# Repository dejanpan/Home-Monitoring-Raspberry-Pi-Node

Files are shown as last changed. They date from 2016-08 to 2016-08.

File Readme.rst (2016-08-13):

----------
Smart Home
----------
In the last month I finally had some spare to scratch the surface on the latest of web backend and frontend development. In particular I got my fingers wet with nodejs and javascript. Back from where I originally come we love the saying `join useful and pleasant` and so I went and built a very custom and cheap **smart home system**. A system that guards our flat, watches over the fridge content and lets us control the lights through a convenience of a cell phone. Sounds cool? Lets take a tour then.

-------------
Home Security
-------------
You type in the web address of our home server (RaspberryPI) and you are offered the following selection:

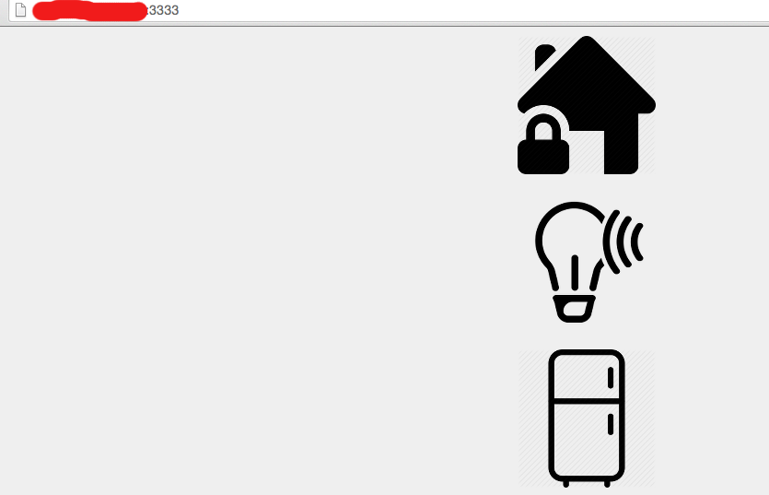
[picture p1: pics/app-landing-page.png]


Lets get to know our security guard (PI, PI camera and PIR motion sensor).

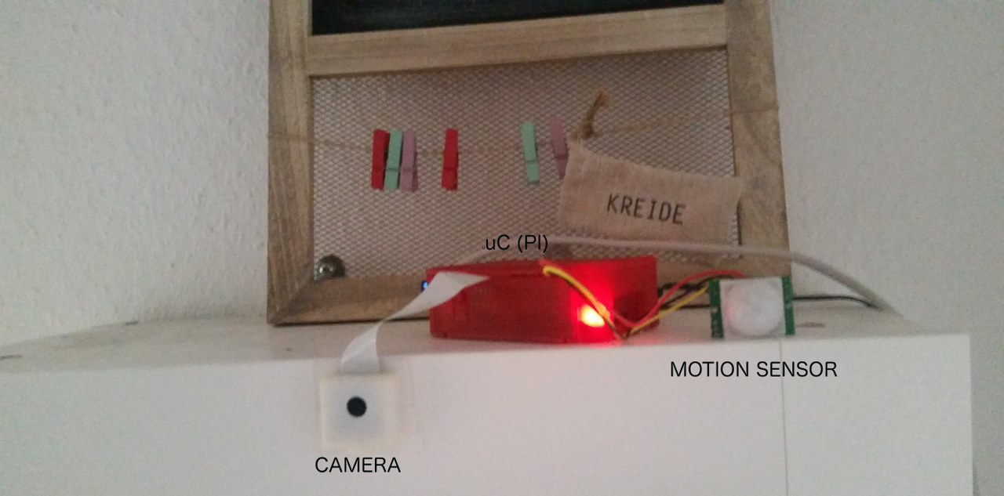
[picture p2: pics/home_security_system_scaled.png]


Interface offers live view into the appartment, switch to arm/disarm an alarm and link to the recorded snapshots whenever the alarm got triggered. The motion sensor senses a change of temperature as soon as someone enters through the door.

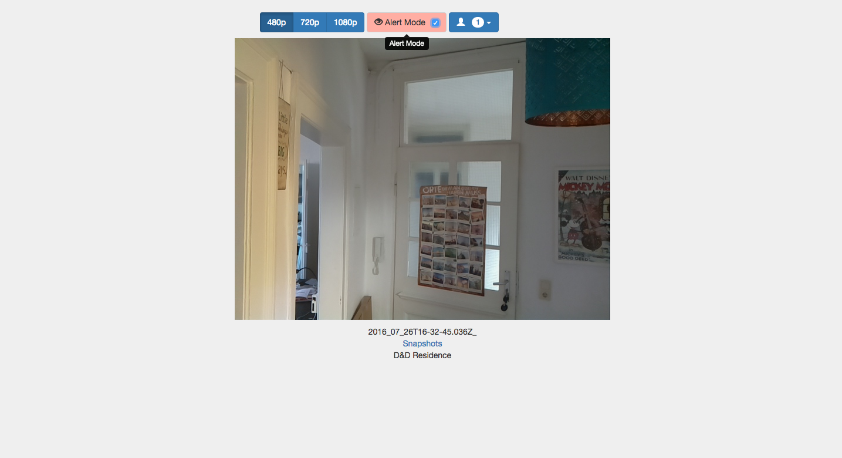
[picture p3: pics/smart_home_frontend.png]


It also sends emails



and comes with the gallery to watch burglars whenever you are bored

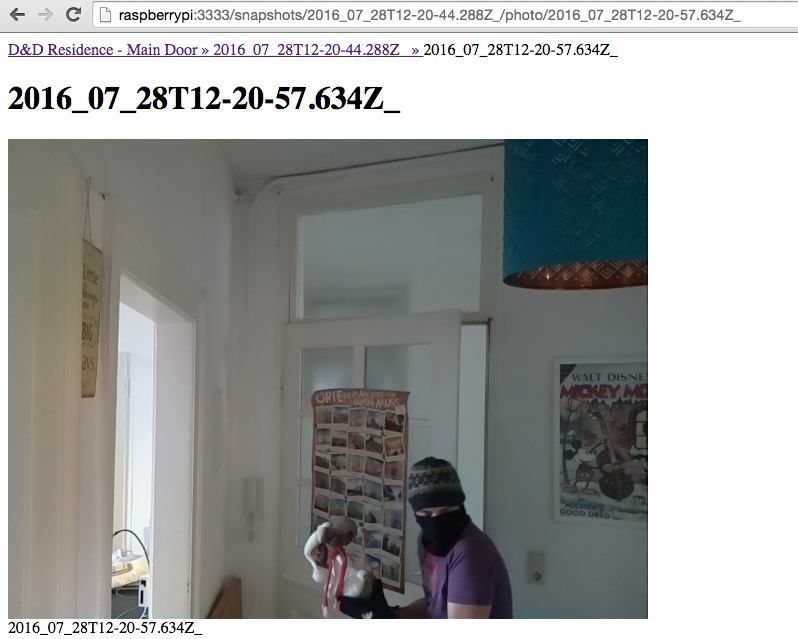
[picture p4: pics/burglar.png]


---------------------
What is in my Fridge
---------------------

Do you know this feeling when you stand in the supermarket and scratch your head trying to remember if you have milk in your fridge? Smart home to the rescue and no more scratching! Lets go back to the landing page:



Click on fridge icon and ... you will end up in our fridge gallery:

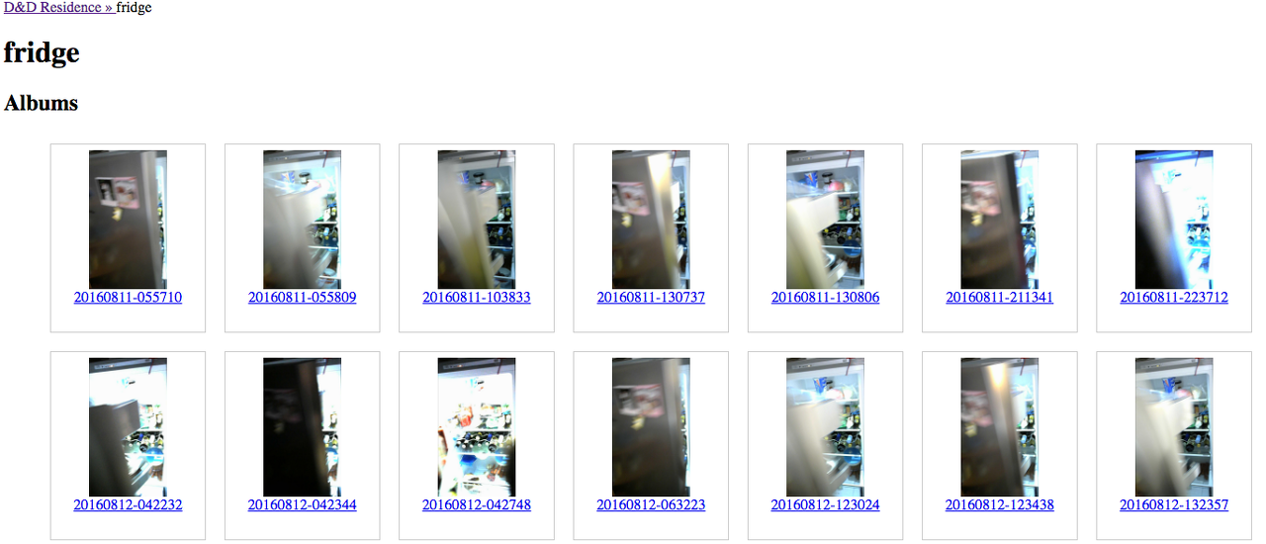
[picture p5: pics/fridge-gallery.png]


So is milk there? Nope! Remember I am watching this from the supermarket:)

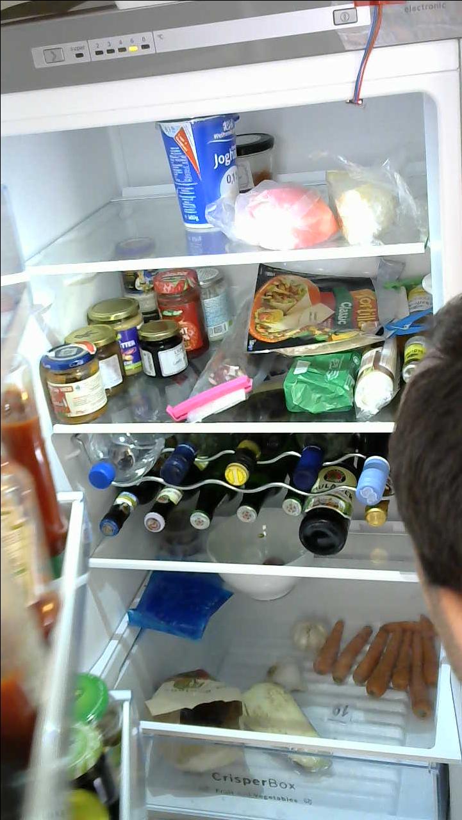
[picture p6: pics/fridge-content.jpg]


How does it work? Assuming you have a fridge, you order a PI:

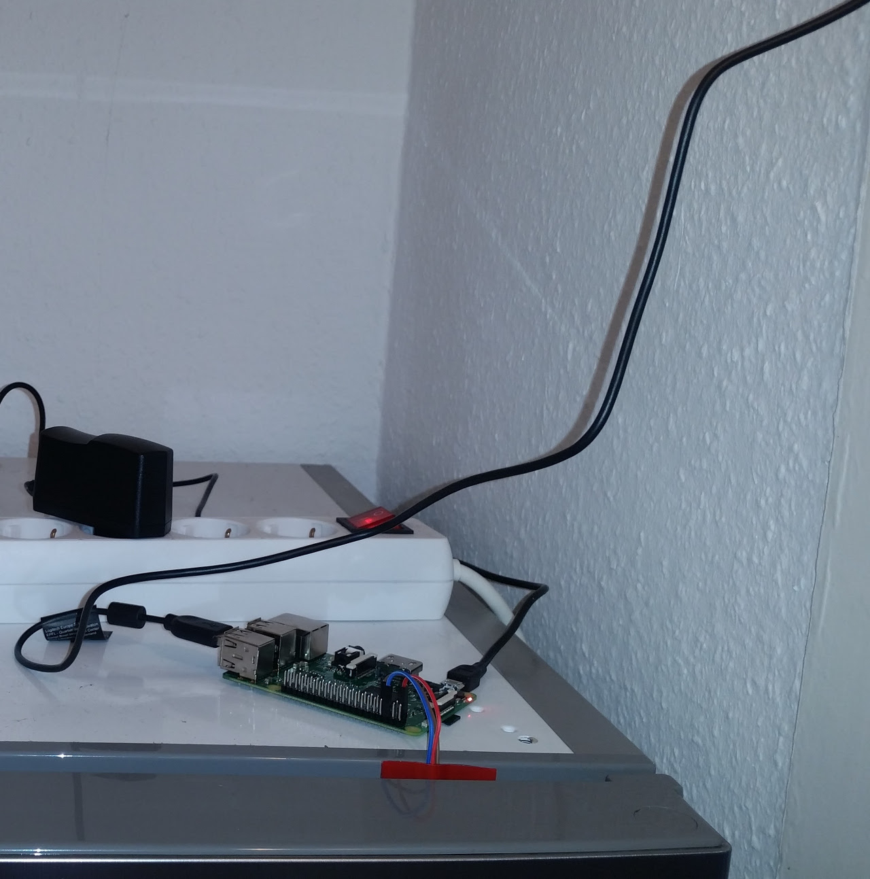
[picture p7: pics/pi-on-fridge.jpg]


a web cam

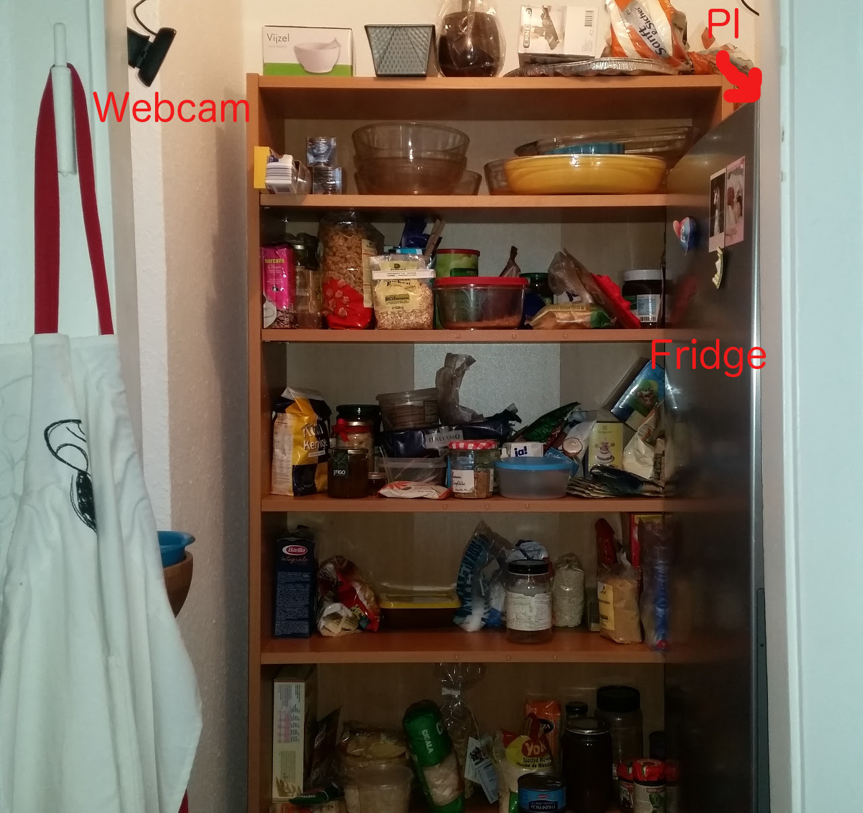
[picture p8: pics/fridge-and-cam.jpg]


a light sensor and voila here you go. Every time you open the fridge, the light inside is turned on and this event triggers recording of fridge images until the fridge is closed again (and thus the light turned off).

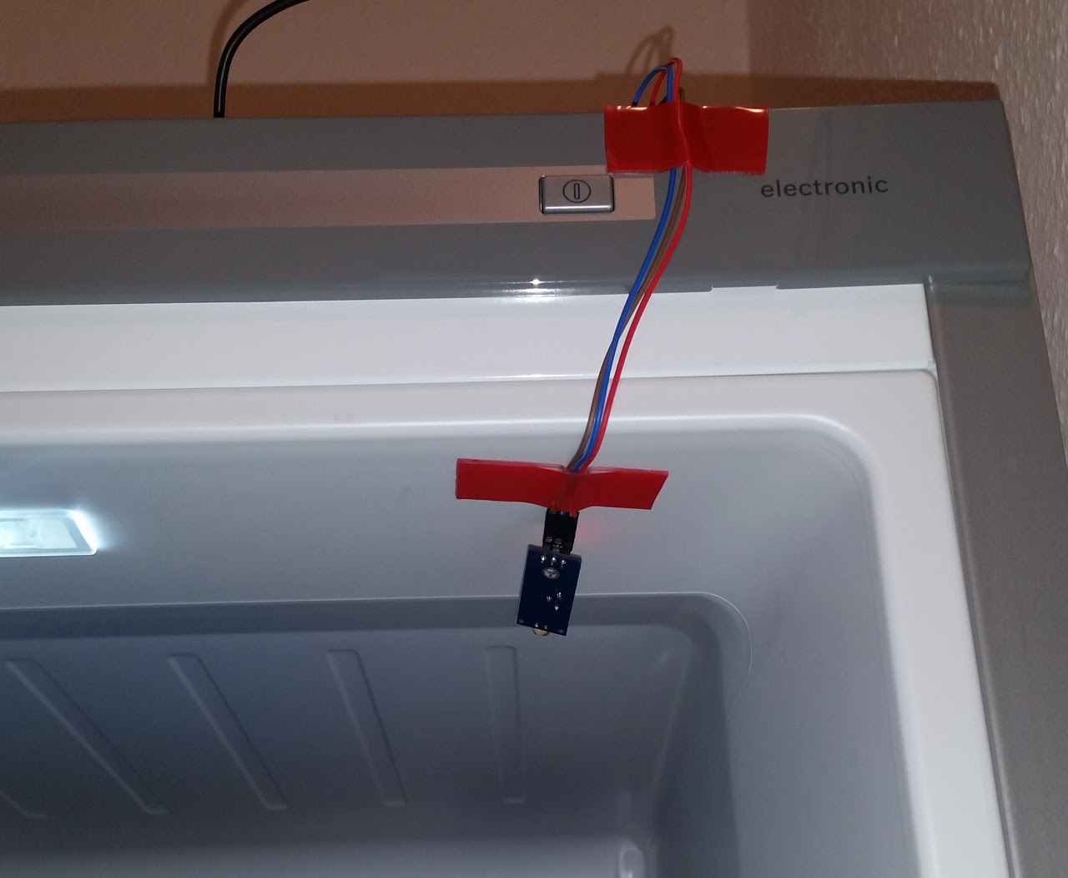
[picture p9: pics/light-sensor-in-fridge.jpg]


-------------------
Remote Light Switch
-------------------
How about that feeling when you are wrapped in the blanket in your bed and the light is still turned on? Worry not, we have a solution for this too. Back to landing page 



and after clicking on the bulb icon you can turn off the light from your cell phone.

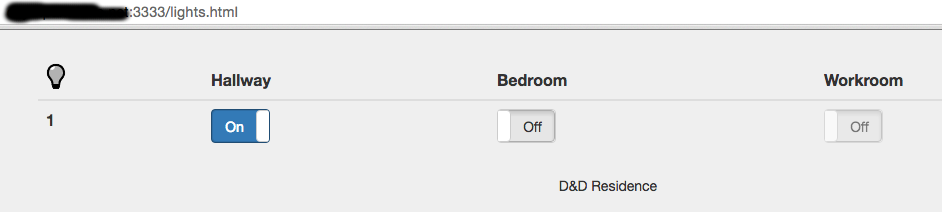
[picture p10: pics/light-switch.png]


.. Now it is bright:
	
  

.. and now it is dark:

  

Remote light switch ensemble:

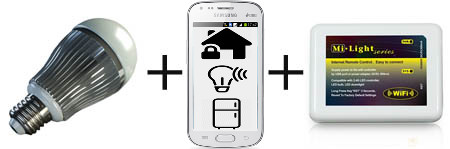
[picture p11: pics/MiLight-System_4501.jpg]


For technical implementation and details see: `documentation <documentation.rst>`_.

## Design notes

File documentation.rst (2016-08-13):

Software part of this project is based on the excellent project of `Andrei <https://github.com/orosandrei/Home-Monitoring-Raspberry-Pi-Node>`_. That was a great jump start.

Below is a list of things that I need to thoroughly document when I get some more time (return from vacations).

-----------
Install PI
-----------
- https://www.raspberrypi.org/documentation/installation/noobs.md
- change hostname in /etc/hosts and /etc/hostname
- apt-get dist-upgrade
- apt-get install emacs
- apt-get install tmux
- git clone https://github.com/jacksonliam/mjpg-streamer.git
- sudo apt-get install cmake
- sudo apt-get install libjpeg9-dev
- sudo apt-get install python-yaml

-----------
Unsorted
-----------
- Light sensor: http://www.uugear.com/portfolio/using-light-sensor-module-with-raspberry-pi/
- Domain name and no-ip
- gpio-admin:

  - https://www.npmjs.com/package/pi-gpio
  - fix for the path: https://github.com/quick2wire/quick2wire-gpio-admin/pull/6
  - Needed to install pi-gpio version 0.0.8 because of this line: https://github.com/rakeshpai/pi-gpio/commit/c6495b0b4f3756a0ec55a6e3d98b7f71b2cb5822

- pinout: https://pinout.xyz/
- setting up vsftp: http://www.liquidweb.com/kb/how-to-install-and-configure-vsftpd-on-ubuntu-14-04-lts/
- mjpeg-streamer:  https://github.com/dejanpan/Home-Monitoring-Raspberry-Pi-Node/commit/08873e3a4a110bb7183767243f2630ab9c6e41fb
- Test programs:

  - ftp
  - test pin out
  - pir.py
  - See https://github.com/dejanpan/Home-Monitoring-Raspberry-Pi-Node/tree/master/test-programs

- Motion detection is recognised as 1
- Milight: http://iqjar.com/jar/home-automation-using-the-raspberry-pi-to-control-the-lights-in-your-home-over-wi-fi/

----------
Framework
----------
- short architecture explanation
- what is express, node-gallery, http, nodemailer, socket.ip, pi-gpio, node-milight-promise
- configuration file

-----------------------------
Home Server and Accessibility
-----------------------------
- register domain
- install client on your raspberry
- crontab job

- image streaming (mjpg-streamer)
- for computer and mobile (bootstrap)
- motion detection
- email notification about intrusion
- snapshots during intrusion (node-gallery)

- milight bulb
- milight controller
- bootstrap-toggle

- image streaming (mjpg-streamer)
- light detection
- moving awvrage window
- python and subprocess
- rsync image upload
- snapshots while the fridge was open (node-gallery)
- wideangle camera and case

-----------------------------
Are my Windows/Doors Closed?
-----------------------------
- zwave magnetic switch
- zwave stick

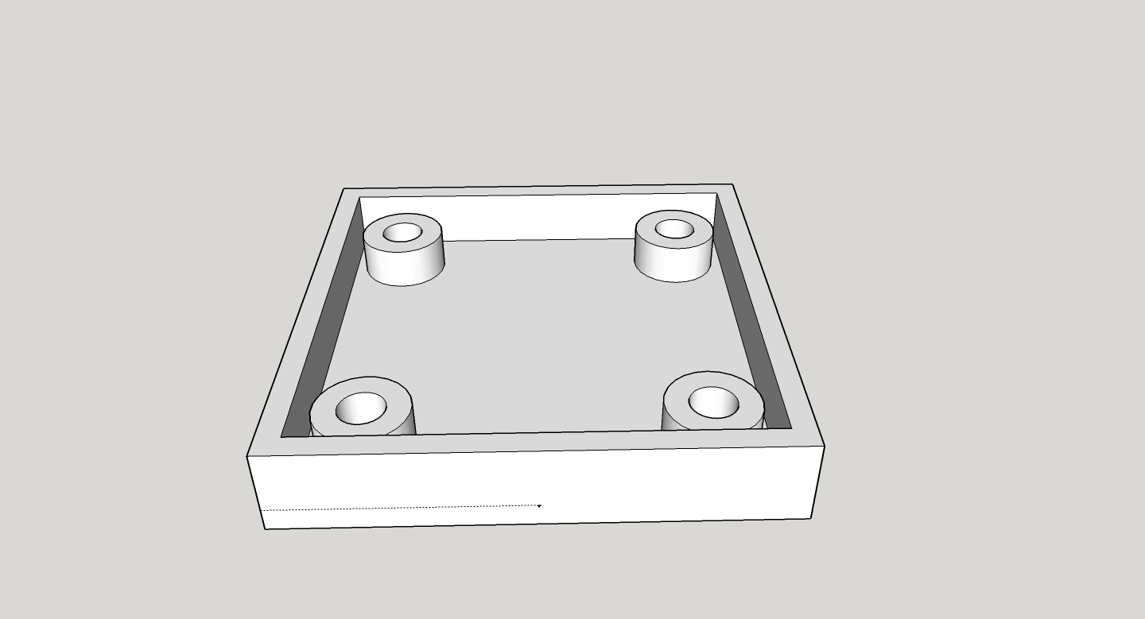
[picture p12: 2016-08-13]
pics/flp_wide_angle_cam_case.jpg

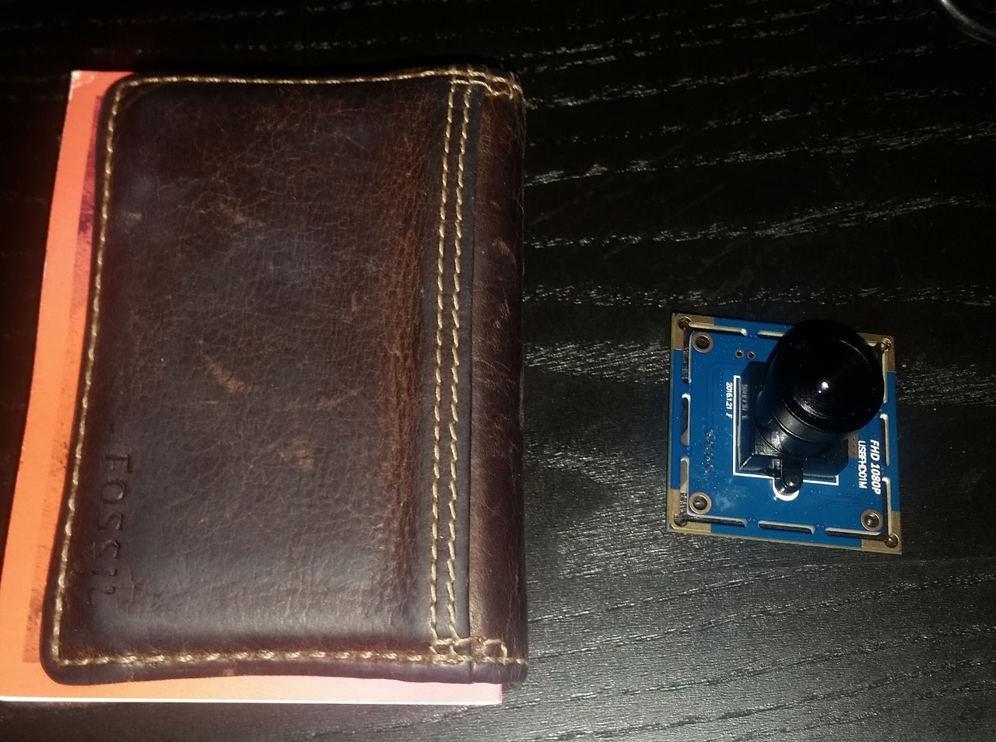
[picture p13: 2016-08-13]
pics/wideangle-cam.jpg

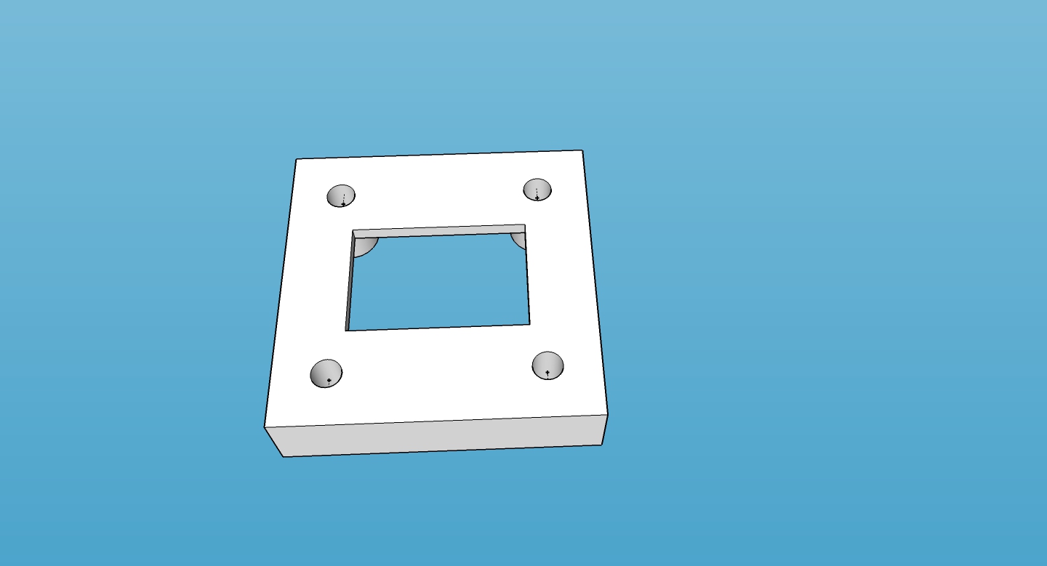
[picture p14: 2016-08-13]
pics/flp_wide_angle_cam_case_top.jpg

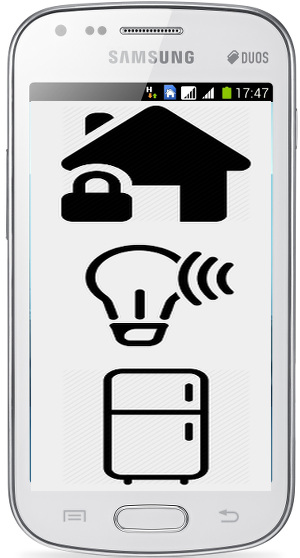
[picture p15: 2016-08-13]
pics/cellphone.jpg

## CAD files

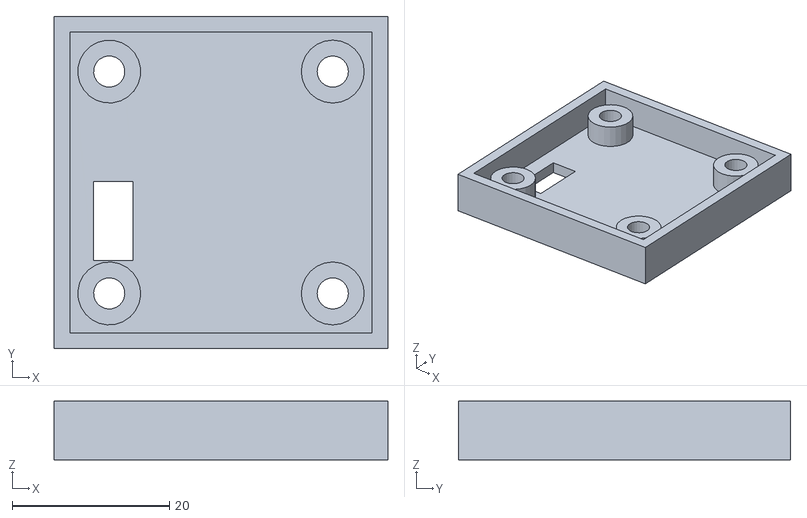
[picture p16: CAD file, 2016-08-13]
pics/flp_wide_angle_cam_case_group.stl
42.4 x 42.2 x 7.50

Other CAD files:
pics/flp_wide_angle_cam_case_group_fixed.stl
pics/flp_wide_angle_cam_case.stl
pics/flp_wide_angle_cam_case.skp
pics/flp_wide_angle_cam_case_top.skp

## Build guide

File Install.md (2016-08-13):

# Home Monitoring with Raspberry Pi and Node.js
 
Home Monitoring with Raspberry Pi and Node.js
 
## Description  
 
The project is designed as a end to end solution for a DIY **Home Monitoring & Intruder Alert system**. Besides offering a live video stream on any device (web responsive client), it also actively monitors for movement with the help of a *PIR sensor*.
 
If an *Alarm* is triggered, you get a SMS notification on your phone and the snapshots taken during the *Alarm time span* (customizable - default is 1 minute) are uploaded via FTP to your server.  
 
Activation / Deactivation of the *Alarm Mode* can be done in 2 ways:  
 1. from the Web Client user interface 
 2. with a Button - for convenience reasons: it is faster than connecting from your phone / pc & toggling the Alert Mode checkbox 
    - there is a 10 seconds customizable delay which allows you to move out of the PIR sensor range 
    - a Led indicates the Alarm Mode enabled/disabled status 
 
In order to avoid false positives from the PIR motion sensor, extra checks were added - a detection counter & detection interval. The Alarm gets triggered when the sensor detects movement 3 times in 5 seconds (both values configurable in code).
 
## Technology 
 
The project was developed using: 
- [Raspberry Pi](http://raspberrypi.org) - [raspbian](https://www.raspbian.org/), brick button & led, Pir sensor
- [Node.js](https://nodejs.org/en/) - for the main application 
- [Mjpg_streamer](http://sourceforge.net/projects/mjpg-streamer/) - to generate the video stream 
- Shell scripting - for easy application start (interactive & background) 
- Htms/Css/Javascript + [Bootstrap](http://getbootstrap.com/) - the web client  
 
## Project components 
 
### Hardware 
Pir Button Led RaspberryPi Gpio
```javascript
this.Gpio = require('pi-gpio');
this.Hardware = { MotionSensor : 8, Led : 26, Button : 12 };
```
- Raspberry Pi 
  - I used *Model B Revision 2* with *Raspbian* - any model should be Ok, just be careful with the Gpio configuration pin mappings, they can differ 
  - Generic USB webcam (compatible with Raspberry Pi & Raspbian) 
  - You can find a comprehensive list here http://elinux.org/RPi_USB_Webcams  
  - I used a very old 2MP one which seems to work out of the box with the generic drivers 
- Led & Button  
Brick Button Led
- PIR motion sensor 

PIR sensor
  - The one I used is available here https://www.sparkfun.com/products/13285  
  - It normally connects to Analog Input (ex. on Arduino); however you can use it with Digital as well if you connect a 10K resistor between VCC & Signal  
PIR resistor 
  - To make things easier you can purchase this sensor https://www.adafruit.com/products/189 and skip the soldering part (+ this one has configurable sensitivity built-in, so you might be able to skip the one implemented in the code)    
 
### Node application 
 
#### Dependencies 
- express: ^4.12.3 
- ftp: ^0.3.10 
- http-auth: ^2.2.8 
- ini: ^1.3.4 
- pi-gpio: 0.0.7 
- socket.io: ^1.3.5 
- twilio: ^2.3.0 
 
The dependencies you install with NPM: 
```
npm install module --save
```
 
#### Generic ```Application.js```
It is the basic application object, defined to be reusable in other projects 
Contains the basic server code, generic config file read/write operations, generic Init & Execute & Exit methods implementations 
 
#### Home Monitoring ```ApplicationHM.js``` 
- config.ini file 
  - default video quality & alert mode settings
  - Twilio sms Api *Sid*, *Token*, *To* number, *From* number 
  - Ftp settings
- Authentication (digest http authentication) - defaults are **admin** & **password** :) 
  - You can change them from the ```htdigest``` file (nice helper tool here http://websistent.com/tools/htdigest-generator-tool/ ) 
  ```
  admin:Private:6982db7f1ddc36a0b47b5f8427dc3526
  ```

- Web Client application
  - Accessible from anywhere via [port forwarding](https://en.wikipedia.org/wiki/Port_forwarding)
  - Available also on mobile (responsive web client) 
- Monitoring - gets video from [Mjpg_streamer](http://sourceforge.net/projects/mjpg-streamer/) server and sends it to the connected app clients 
- [Mjpg_streamer](http://sourceforge.net/projects/mjpg-streamer/) was used as server, but if you prefer another tool like ffmpeg, you can easily replace it because of the loose integration via the ```start-webcam.sh``` script 

#### Alarm mode 
- Monitoring - via PIR sensor 
- Alarm - Sms notification (implemented with the help of [Twilio](https://www.twilio.com/sms)   text messaging API - very cool service, offers great Trial account for development 
- Alarm - Snapshots upload to server via Ftp 
 
### Web Client - responsive
 
The client application was designed to be accessible on all platforms (pc / tablet / mobile). 

Web Client  

#### Video streaming quality settings 
By default the 480p at 25fps is enabled (initial settings are loaded from the ```config.ini``` file) 

My webcam is a low-end 5+ years old 2mp device, but for those of you with better webcams I also added 720p & 1080p 

Video resolutions & fps can be configured from the ```/static/js/script.js``` file 
```javascript
//only check quality settings
if(ui.quality480p.prop('checked')) {
	appConfig.monitoring.quality = "640x480";
	appConfig.monitoring.fps = 25;
}
if(ui.quality720p.prop('checked')) { 
	appConfig.monitoring.quality = "1280x720";			
	appConfig.monitoring.fps = 25;
}
if(ui.quality1080p.prop('checked')) { 
	appConfig.monitoring.quality = "1920x1080";			
	appConfig.monitoring.fps = 25;
}
	
//send to server new config settings
socket.emit('update config quality', appConfig);
```
 
#### Alert Mode 
- initial state is loaded from the ```config.ini``` file 
- You can enable/disable monitoring from checkbox button in the UI 
- The state of the Alert Mode is shown both in the UI (the checkbox) but also by the LED 
- The physical Button can be also used to toggle the Alert Mode 
- All state changes are sent to all connected clients 
- If an Alarm is triggered, the UI checkbox button background will be changed to Red 
Alarm  

#### Connected Clients 
The dropdown shows a list of all connected clients (connection timestamp & IP) that are currently viewing the video stream  
Connected Clients List  

### Shell Scripts 
 
**start-app.sh**
- You can start the application in 2 modes: 
  - Interactive (for dev / testing): ```./start-app.sh```
  - Background: ```./start-app.sh -background```
```shell
#!/bin/bash
# application start in interactive or background mode
#arguments:  [-background]

cd /home/pi/Desktop/rpiWorkspace/Node/HomeMonitoring/

if [ "$1" = "-background" ]; then
	sudo nohup node ./App-home-monitoring.js &>log.txt &
else
	sudo node ./App-home-monitoring.js 
fi
```
  
**start-webcam.sh**
- Used by the application to enable/disable video streaming when clients are connected or when an Alarm is triggered by the PIR sensor. 
```shell
#!/bin/bash
# webcam video stream
# arguments:  [resolution] [port] [fps]

pkill mjpg_streamer

sudo nohup ./mjpg-streamer/mjpg_streamer -i "./mjpg-streamer/input_uvc.so -y -r $1 -f $3 -q 75" -o "./mjpg-streamer/output_http.so -n -p $2" &
```

## Application Execution Session example
Application Execution Session example  

---
 
**TO DO** 
- Port the application to Windows 10 Iot on Raspberry Pi 2 
- Support for uploading snapshots to cloud (OneDrive / Dropbox) when an Alarm is triggered 
 
**References** 
- Raspberry Pi https://www.raspberrypi.org/  
- Node - https://nodejs.org/en/  
- Mjpg_streamer http://sourceforge.net/projects/mjpg-streamer/  
- SMS Api - Twilio - https://www.twilio.com/sms  
- Bootstrap http://getbootstrap.com/ 
- App Webcam Icon - https://www.iconfinder.com/icons/71274/webcam_icon#size=128  

---
**Links**
- Blog post about project [Home Monitoring with Raspberry Pi & Node](http://andreioros.com/blog/home-monitoring-raspberry-pi-node/%20)
- [Hackster.io project page](https://www.hackster.io/andreioros) 
- twitter [@orosandrei](https://twitter.com/orosandrei)

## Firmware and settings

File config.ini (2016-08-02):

[monitoring]
alert=false
fps=10
width=640
height=480

[sms]
sid=
token=
to=
from=

[ftp]
server=localhost
port=21
user=ftpup
pass=ftpup
folder=/home/ftpup/

[email]
user=
password=
from=
to=
subject=
text=

[lights]
ip=192.168.178.54
delayBetweenCommands=75
commandRepeat=2

[lights.rooms.bedroom]
zone=2
name=bedroom
state=false

[lights.rooms.hallway]
zone=1
name=hallway
state=false

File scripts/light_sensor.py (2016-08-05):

import time
import datetime
import RPi.GPIO as GPIO
import subprocess
import sys, os
import yaml
import shutil
import math

from PIL import Image
import glob

from collections import deque
light_reading_cache = deque() # keep track of seen values
cum_sum = 0

def print_help():
        print("""
        Usage: light_sensor.py config.yaml
        """)

def load_config(file):
        with open(file, 'r') as stream:
                try:
                        config  = yaml.load(stream)
                except yaml.YAMLError as exc:
                        print(exc)
        return config

def configure_sensor(pin):
        GPIO.setmode(GPIO.BCM)
        GPIO.setup(pin,GPIO.IN)

#bright is low, dark is high
def is_light_on(counter, window_size, pin):
        if filter_signal(GPIO.input(pin), counter, window_size) == 0:
                return True
        else:
                return False

def filter_signal(val, counter, window_size):
        global cum_sum
        light_reading_cache.append(val)
        cum_sum += val
        if counter < window_size:
                avg = cum_sum / float(counter)
                round_avg = int(round(avg))
        else:                           # if window is saturated,
                avg = cum_sum / float(window_size)
                cum_sum -= light_reading_cache.popleft()  # subtract oldest value
                round_avg = int(round(avg))
        return round_avg
                
def upload_snapshots(config, src):
        key = os.path.expanduser(config['ssh_key'])
        ssh  = 'ssh -i {}'.format(key)
        path = config['remote_path']
        print os.path.join(src,"")
        cmd = [ 'rsync', '-vaP',  '--progress', '-e', ssh,
                src, '{}@{}:{}'.format(config['user'], config['host'], os.path.join(path,"")) ]
        subprocess.check_call(cmd)

def rotate_snapshots(dirname, angle):
        for infile in glob.glob(dirname + "/*.jpg"):
                print("rotating ", infile)
                im = Image.open(infile)
                im.rotate(angle, expand=True).save(infile, 'JPEG')
        
def process(config):
        configure_sensor(config['pinout'])
        new_snapshots = False
        try:
                print("starting mjpg-streamer")
                cmd = [ config['script'], config['resolution'], str(config['fps']), str(config['port']) ]
                proc_mjpg = subprocess.Popen(cmd)
                counter = 1
                while True:
                        if is_light_on(counter, config['window_size'], config['pinout']):
                                #where to save images
                                dirname = time.strftime("%Y%m%d-%H%M%S")
                                if not os.path.exists(dirname):
                                        os.makedirs(dirname)
                                        
                                t_end = time.time() + config['snapshot_duration']

                                #grab snapshots
                                while is_light_on(counter, config['window_size'], config['pinout']):
                                        image_name = dirname + '/' + datetime.datetime.now().strftime("%Y%m%d-%H%M%S-%f") + '.jpg'
                                        wget_proc = subprocess.call(['wget',  'http://localhost:' + str(config['port']) + '/?action=snapshot', '-O', image_name], shell=False)
                                        time.sleep(1/config['fps'])
                                        new_snapshots = True
                                        
                        #upload them to main server (rsync)
                        if new_snapshots:
                                rotate_snapshots(dirname, config['angle'])
                                upload_snapshots(config, dirname)
                                shutil.rmtree(dirname)
                                new_snapshots = False
                                
                        #avoid counter overflow
                        if counter >= config['window_size']:
                                counter = 2 * config['window_size'] #could be any value > window size
                        
                        counter = counter + 1
                        time.sleep(0.1)
        except KeyboardInterrupt:
                print("Received KeyboardInterrupt, terminating processes.")
        finally:
                if proc_mjpg is not None and proc_mjpg.poll() is None:
                        try:
                                proc_mjpg.terminate() # send terminate signal
                                proc_mjpg.communicate() # wait for the process to terminate
                                subprocess.call(['pkill', 'mjpg_streamer']) #above 2 lines do not kill mjpg-streamer                      
                        except:
                                print("Failed to terminate process with PID %s: %s" % (proc_mjpg.pid, sys.exc_info()[0]))

if __name__ == '__main__':
        if len(sys.argv) != 2:
                print_help()
                exit(-1)
        config = load_config(sys.argv[1])
        process(config)
        # signal = [0, 0, 0, 0, 0, 1, 1, 1, 1, 1, 1]
        # counter = 1
        # for i in signal:
        #         print(filter_signal(i, counter))
        #         counter = counter + 1
                

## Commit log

2016-07-13 fixed starting of the app from nodejs application
    [config.ini]
2016-07-14 full frame display works now, however it is laggy (it seems that we sometimes do not get valid jpeg frames) and I think there is a memory leak now in
2016-07-14 concatenating all frames with pattern 65k 65k 20k
2016-07-24 start-webcom can now be started from nodejs and passing arguments from there too. Also fix for raspberrypi plugin which does not support -r parameter.
    [config.ini]
2016-07-25 testing scripts for my case
2016-07-25 my version of raspbian (Linux raspberrypi 4.4.11-v7+ #888) requires version 0.0.8
2016-07-25 re-introduced pir sensor sensing and alarm triggering
2016-08-01 bootstrap toggle for toggle button
2016-08-02 turn on light while camera is recording in alarm mode
2016-08-02 restructured framework into 3 sections: security, lights and fridge. nothing super new, just a whole bunch of html files and icons
2016-08-03 python script that reacts to light sensor in the fridge, grabs images once someone opened the door and uploads them to the main server
2016-08-04 added movinf avg filter for the case of outliers
2016-08-04 removed print
